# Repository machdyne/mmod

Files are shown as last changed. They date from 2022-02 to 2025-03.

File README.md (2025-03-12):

# MMOD

## Overview

MMOD is a 3.3V SPI memory module used in Machdyne / Lone Dynamics computers in order to allow for user-replaceable and user-upgradeable memory. The module is inserted into the MMOD socket with the top-side components facing the host board.

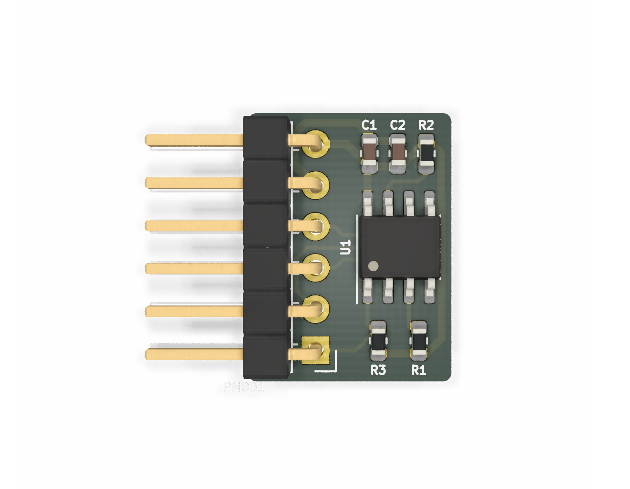
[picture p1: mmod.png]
MMOD


MMOD modules are compatible with Pmod&trade; Interface Type 2 (SPI) and can be used in 6 or 12 pin Pmod&trade; sockets, but Pmod modules are not necessarily compatible with MMOD sockets due to differences in size and requirements.

This repo contains specifications, pinouts, footprints, schematics and PCB layouts.

Find more information on the [MMOD product page](https://machdyne.com/product/mmod/).

## Pinout

| Pin | Signal |
| --- | --- |
| 1 | SS |
| 2 | MOSI |
| 3 | MISO |
| 4 | SCK |
| 5 | GND |
| 6 | PWR3V3 |

## Dimensions

Width: 16.5mm (parallel with header)

Length: 12.5mm max (perpendicular to header)

Height: 8mm max (top of header to top of bottom-side components)

## MMOD Board Requirements

- The top-side components must not touch the host board.
- The module must not interfere with the SPI bus unless SS is asserted (low).
- The module should provide decoupling capacitors for the memory.
- The module should provide any necessary pull-up/down resistors for the memory.
- SPI SS should be pulled high with a 10K resistor.
- SPI MOSI, MISO and SCK should have no pull-up/down resistors.
- The module must not draw more than 50mA current at any time.

## MMOD-D (Type-D) Additional Requirements

MMOD-D is a special type of MMOD containing two SPI devices, the requirements are the same as MMOD but with the following differences:

- The SPI bus is expected to be dedicated to the MMOD.
- The module may interfere with the SPI bus regardless of the state of SS.

## License

The contents of this repo are released under the [Lone Dynamics Open License](LICENSE.md) with the following exceptions:

- The KiCad design files contain parts of the [kicad-pmod](https://github.com/mithro/kicad-pmod) library which is released under the [Apache License, Version 2.0](https://www.apache.org/licenses/LICENSE-2.0.html).

Note: You can use these designs for commercial purposes but we ask that instead of producing exact clones, that you either replace our trademarks and logos with your own or add your own next to ours.

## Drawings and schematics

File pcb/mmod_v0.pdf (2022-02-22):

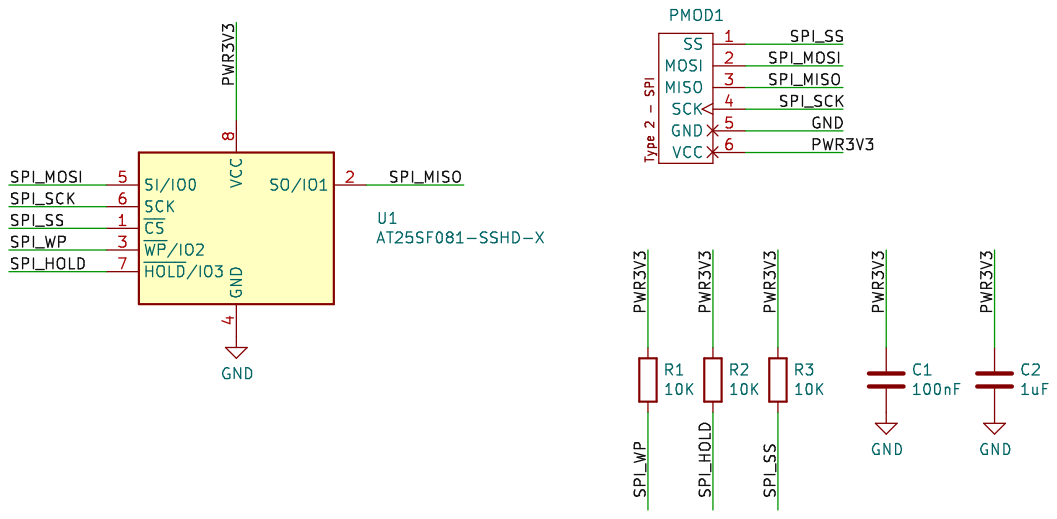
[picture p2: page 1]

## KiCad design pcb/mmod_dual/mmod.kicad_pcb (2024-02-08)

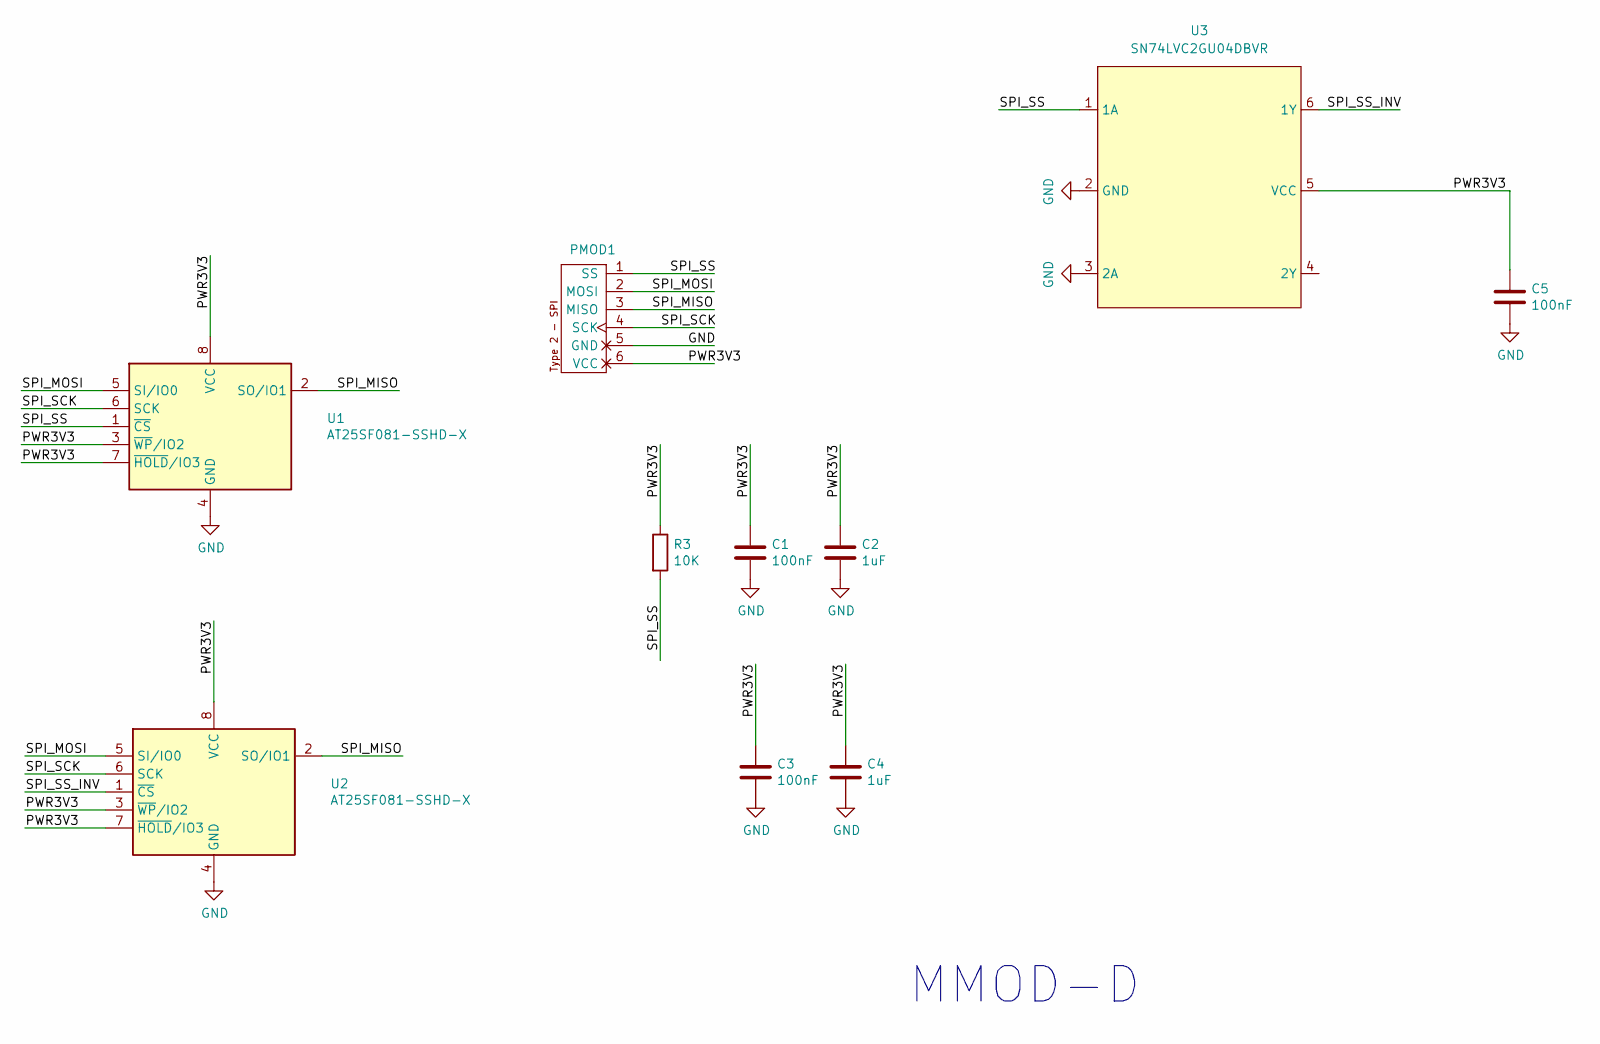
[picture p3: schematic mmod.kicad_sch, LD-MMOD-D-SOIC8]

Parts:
C1, C3: 100nF; C_0402_1005Metric
C2, C4: 1uF; C_0402_1005Metric
C5: 100nF; C_0402_1005Metric_Pad0.74x0.62mm_HandSolder
PMOD1: PMOD-Device-x1-Type-2-SPI; PinHeader_1x06_P2.54mm_Horizontal
R3: 10K; R_0402_1005Metric
U1, U2: AT25SF081-SSHD-X; SOIC-8_3.9x4.9mm_P1.27mm
U3: SN74LVC2GU04DBVR; SOT-23-6_Handsoldering

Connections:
/PWR3V3: C1.1, C2.1, C3.1, C4.1, C5.1, PMOD1.6 (VCC), R3.1, U1.3 (~WP/IO2), U1.7 (~HOLD/IO3), U1.8 (VCC), U2.3 (~WP/IO2), U2.7 (~HOLD/IO3), U2.8 (VCC), U3.5 (VCC)
/SPI_MISO: PMOD1.3 (MISO), U1.2 (SO/IO1), U2.2 (SO/IO1)
/SPI_MOSI: PMOD1.2 (MOSI), U1.5 (SI/IO0), U2.5 (SI/IO0)
/SPI_SCK: PMOD1.4 (SCK), U1.6 (SCK), U2.6 (SCK)
/SPI_SS: PMOD1.1 (SS), R3.2, U1.1 (~CS), U3.1 (1A)
/SPI_SS_INV: U2.1 (~CS), U3.6 (1Y)
GND: C1.2, C2.2, C3.2, C4.2, C5.2, PMOD1.5 (GND), U1.4 (GND), U2.4 (GND), U3.2 (GND), U3.3 (2A)

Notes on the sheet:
MMOD-D

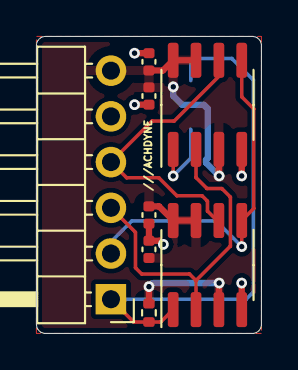
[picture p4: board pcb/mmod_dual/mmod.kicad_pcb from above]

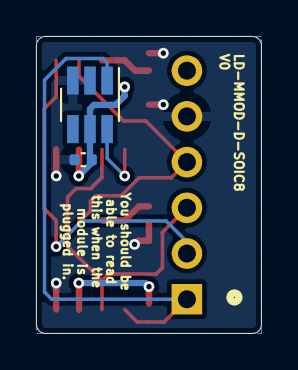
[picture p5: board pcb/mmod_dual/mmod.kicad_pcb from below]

Board: 2 copper layers, 12.5 x 16.5 mm, 10 parts (2 on the bottom side), 7 nets.

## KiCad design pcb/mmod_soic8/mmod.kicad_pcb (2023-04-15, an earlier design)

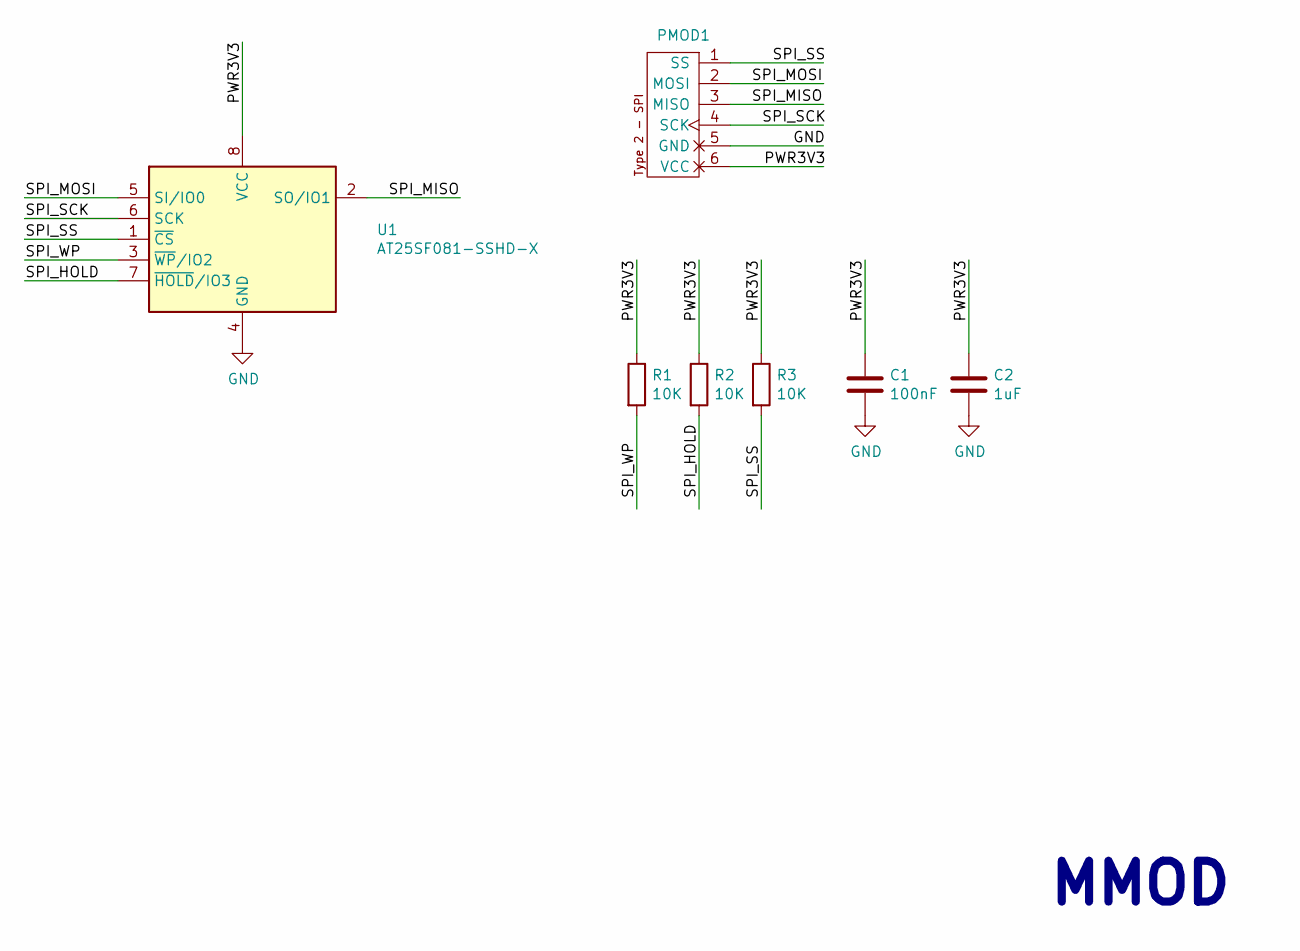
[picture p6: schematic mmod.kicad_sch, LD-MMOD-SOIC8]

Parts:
C1: 100nF; C_0603_1608Metric
C2: 1uF; C_0603_1608Metric
PMOD1: PMOD-Device-x1-Type-2-SPI; PinHeader_1x06_P2.54mm_Horizontal
R1, R2, R3: 10K; R_0603_1608Metric
U1: AT25SF081-SSHD-X; SOIC-8_3.9x4.9mm_P1.27mm

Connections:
/PWR3V3: C1.1, C2.1, PMOD1.6 (VCC), R1.1, R2.1, R3.1, U1.8 (VCC)
/SPI_HOLD: R2.2, U1.7 (~HOLD/IO3)
/SPI_MISO: PMOD1.3 (MISO), U1.2 (SO/IO1)
/SPI_MOSI: PMOD1.2 (MOSI), U1.5 (SI/IO0)
/SPI_SCK: PMOD1.4 (SCK), U1.6 (SCK)
/SPI_SS: PMOD1.1 (SS), R3.2, U1.1 (~CS)
/SPI_WP: R1.2, U1.3 (~WP/IO2)
GND: C1.2, C2.2, PMOD1.5 (GND), U1.4 (GND)

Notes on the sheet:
MMOD

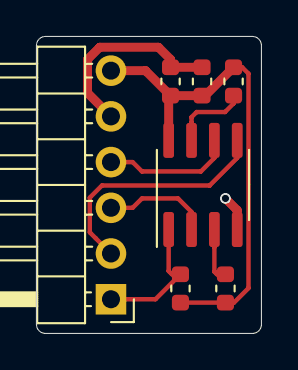
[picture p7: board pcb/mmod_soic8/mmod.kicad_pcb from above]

Board: 2 copper layers, 12.5 x 16.5 mm, 7 parts (0 on the bottom side), 8 nets.

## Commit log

2023-04-15 add pcb layouts
    [mmod.kicad_pcb, mmod.kicad_sch, mmod_wson.kicad_pcb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]
2023-11-13 add soic8 wide
    [mmod.kicad_pcb, mmod.kicad_sch]
2024-02-08 add MMOD-D pcb layout
    [mmod.kicad_pcb, mmod.kicad_sch]

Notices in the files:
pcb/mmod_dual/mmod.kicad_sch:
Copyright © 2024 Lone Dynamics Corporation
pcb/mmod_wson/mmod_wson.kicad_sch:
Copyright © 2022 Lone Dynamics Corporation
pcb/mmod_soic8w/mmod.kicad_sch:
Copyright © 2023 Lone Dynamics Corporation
